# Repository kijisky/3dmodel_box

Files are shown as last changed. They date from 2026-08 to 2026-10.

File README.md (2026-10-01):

# Коробка для хранения метизов

Параметрическая 3D-модель (CadQuery) органайзера для метизов — винтов,
гаек, шайб и т.п. Рассчитана на печать на **ANYCUBIC Kobra S1**
(рабочая область 250×250×250 мм, CoreXY) плашмя, без поддержек.

## Модель сетки отсеков

Коробка делится на **строки** (по Y, вдоль длины). Каждая строка занимает
полную внутреннюю ширину коробки и делится на **свои** колонки (по X) —
независимо от других строк. Это значит:

- у разных строк может быть разное число ячеек;
- ширина каждой ячейки внутри строки задаётся независимо;
- сетка не обязана быть "таблицей" — ячейки соседних строк не обязаны
  совпадать по X.

## Параметры

| Параметр | CLI-флаг | По умолчанию | Описание |
|---|---|---|---|
| Ширина коробки | `--width` | 190 мм | внешний размер по X |
| Длина коробки | `--length` | 130 мм | внешний размер по Y |
| Высота (глубина) коробки | `--height` | 30 мм | внешний размер по Z |
| Толщина стенок | `--wall` | 2 мм | толщина внешних стенок, дна и перегородок |
| Число строк | `--rows` | 4 | строки идут по короткой стороне (Y) |
| Колонок в строке | `--cols` | 6 | одинаковое число колонок для всех строк (по длинной стороне, X) |
| Колонок по строкам | `--row-cols` | — | своё число колонок для каждой строки через запятую, напр. `3,6,6,6`; переопределяет `--cols` |
| Радиус скругления отсеков | `--radius` | 3 мм | скругление внутренних вертикальных углов каждой ячейки |
| Длины строк | `--row-sizes` | равномерно | список мм через запятую (по Y), переопределяет равное деление |
| Ширины ячеек по строкам | `--row-col-sizes` | равномерно | ширины каждой ячейки каждой строки (мм); группы строк разделены `\|`, ширины внутри строки — запятой |

По умолчанию получается коробка 190×130×30 мм: 4 строки по короткой
стороне (130 мм), в каждой строке по 6 колонок вдоль длинной стороны
(190 мм) — 24 одинаковых отсека.

Если заданы `--row-sizes` / `--row-col-sizes`, суммы значений должны точно
заполнять внутреннее пространство за вычетом перегородок:
`sum(sizes) == доступный_размер − толщина_стенки×(N−1)`, где
`доступный_размер = внешний_размер − 2×толщина_стенки`.
При несовпадении скрипт выбросит понятную ошибку с подсказкой.

## Крышка: шарнир + защёлка, стекирование

По умолчанию скрипт генерирует **три** STL: короб, крышку и шпильку
шарнира. Крышка **не снимается целиком** — она навешена на шарнир с одной
(длинной) стороны короба и открывается/закрывается поворотом, как у
чемодана; с противоположной стороны она держится защёлкой-замком, которую
можно отстегнуть.

- **Шарнир** (`hinge_wall`, по умолчанию `south`) — вдоль этой стенки на
  коробе и на крышке формируется ряд чередующихся цилиндрических петель
  (короб/крышка/короб/крышка/короб — `--hinge-knuckle-count`, по
  умолчанию 5), с общим отверстием под стержень. После печати в
  отверстия продевается отдельная деталь-шпилька (`..._pin.stl`,
  диаметр `--hinge-pin-diameter`, по умолчанию 3 мм — подходит кусок
  прутка, гвоздь без шляпки, спица или отрезок толстой лески/прутка от
  3D-принтера) — она и становится осью вращения. Отключается флагом
  `--no-hinge` — тогда крышка снова полностью съёмная, с защёлками со
  всех задействованных сторон (как раньше).
- **Защёлка-замок** — на противоположной шарниру стенке (и по умолчанию
  больше нигде) на внешней стенке короба формируется небольшой
  купол-выступ. В юбке крышки, ровно напротив него, с обеих сторон
  прорезаны узкие щели (`--snap-arm-gap`), отделяющие гибкий язычок
  шириной `--snap-arm-width` от остальной (жёсткой) юбки — держится он
  только сверху, на панели крышки, и может пружинить. На язычке —
  ответное углубление под выступ. Язычок продолжается ниже юбки на
  `--snap-tab-length` мм с небольшим наплывом наружу (`--snap-flare`) —
  этот выступающий кончик хорошо виден и удобно берётся пальцами.
  Чтобы отстегнуть: подцепите/отогните язычок наружу за выступающий
  кончик, пока выступ не выйдет из углубления, и откройте крышку на
  шарнире — инструмент не нужен, защёлка не ломается. Отключается флагом
  `--no-snap` (тогда крышка держится только посадкой с натягом на
  свободных от шарнира сторонах).
- **Стекирование** — на верхней стороне крышки формируется приподнятый
  бортик, внутренний размер которого равен внешнему периметру короба
  (+ зазор `--stack-clearance`). Следующий короб, поставленный сверху,
  дном садится внутрь этого бортика и не соскальзывает — короба стекуются
  друг на друга так же, как если бы каждый следующий просто стоял на
  предыдущем. Отключается флагом `--no-stacking`.

Дополнительные флаги шарнира: `--hinge-wall` (`north`/`south`/`east`/
`west` — какая стенка становится осью), `--hinge-knuckle-diameter`,
`--hinge-knuckle-count`, `--hinge-knuckle-gap` (зазор между соседними
петлями), `--hinge-margin` (отступ ряда петель от боковых стенок),
`--hinge-pin-clearance` (зазор шпильки в отверстии — свобода вращения).

Дополнительные флаги защёлки: `--snap-diameter`/`--snap-height` (размер
купола-выступа), `--snap-long`/`--snap-short` (число защёлок на длинных/
коротких стенках, кроме стенки шарнира), `--snap-arm-width` (ширина
гибкого язычка), `--snap-arm-gap` (ширина прорези, отделяющей язычок),
`--snap-tab-length` и `--snap-flare` (длина и наплыв выступающего кончика
для захвата).

Крышка и шпилька всегда должны генерироваться с теми же `--width/
--length/--height/--wall`, что и короб, к которому они предназначены —
иначе не подойдут.

## Установка

```bash
pip install -r requirements.txt
```

## Генерация STL

```bash
# модель по умолчанию (190x130x30, 4 строки x 6 колонок) + крышка на шарнире + шпилька
python3 models/fastener_box.py --out stl/fastener_box_190x130x30_6x4.stl
# -> ..._6x4.stl (короб), ..._6x4_lid.stl (крышка), ..._6x4_pin.stl (шпилька шарнира)

# шарнир на короткой стенке вместо длинной
python3 models/fastener_box.py --hinge-wall east --out stl/box_east_hinge.stl

# полностью съёмная крышка (без шарнира), как в предыдущей версии модели
python3 models/fastener_box.py --no-hinge --out stl/box_removable_lid.stl

# кастомные габариты и равномерная сетка
python3 models/fastener_box.py --width 200 --length 150 --height 40 \
  --wall 2.5 --rows 3 --cols 5 --radius 4 \
  --out stl/my_box.stl

# разное число ячеек в разных строках: в первой строке 3 широкие ячейки,
# в остальных трёх — по 6 обычных; крышка не нужна — та же, что у базовой модели
python3 models/fastener_box.py --row-cols 3,6,6,6 --no-lid \
  --out stl/fastener_box_190x130x30_mixed_rows.stl

# полностью произвольная сетка: своя высота строки, число ячеек и их
# ширина в каждой строке независимо (не таблица)
python3 models/fastener_box.py --rows 3 \
  --row-cols 2,4,1 \
  --row-sizes 40,42,40 \
  --row-col-sizes "100,84|30,50,40,60|186" \
  --no-lid --out stl/fastener_box_example_freeform.stl

# короб без крышки/защёлок/стекирования — просто открытый лоток
python3 models/fastener_box.py --no-lid --out stl/simple_tray.stl

# без защёлок (только посадка с натягом) или без бортика для стекирования
python3 models/fastener_box.py --no-snap --out stl/box_no_snap.stl
python3 models/fastener_box.py --no-stacking --out stl/box_no_stack.stl

# дополнительно сохранить STEP короба для редактирования в CAD
python3 models/fastener_box.py --step stl/fastener_box.step
```

Модель также можно импортировать программно:

```python
from models.fastener_box import build_fastener_box, build_lid, build_box_and_lid

# равномерная сетка, только короб
model = build_fastener_box(box_width=190, box_length=130, box_height=30,
                            wall_thickness=2, num_rows=4, row_cols=6,
                            corner_radius=3)

# произвольная сетка: 3 строки, разное число ячеек и их ширина в каждой
model = build_fastener_box(
    num_rows=3,
    row_cols=[2, 4, 1],              # число ячеек в каждой строке
    row_sizes=[40, 42, 40],          # высота (по Y) каждой строки
    row_col_sizes=[[100, 84], [30, 50, 40, 60], [186]],  # ширина ячеек в каждой строке
)

# короб + подходящая крышка + шпилька шарнира одним вызовом
# (используют общие box_* параметры; pin равен None при hinge_enabled=False)
base, lid, pin = build_box_and_lid(box_width=190, box_length=130, box_height=30,
                                    row_cols=6, num_rows=4)
```

## Готовые STL в этом репозитории

- `stl/fastener_box_190x130x30_6x4.stl` — короб по умолчанию (4 строки x 6 колонок, равномерная сетка), с петлями шарнира и защёлкой.
- `stl/fastener_box_190x130x30_6x4_lid.stl` — крышка к нему (на шарнире + защёлка + бортик для стекирования).
- `stl/fastener_box_190x130x30_6x4_pin.stl` — шпилька шарнира.
- `stl/fastener_box_190x130x30_mixed_rows.stl` — первая строка из 3 широких ячеек, остальные строки — по 6 обычных (короб напечатан без крышки, `--no-lid`; подходит под ту же крышку/шпильку).
- `stl/fastener_box_example_freeform.stl` — полностью произвольная сетка (разная высота строк, разное число и ширина ячеек в каждой строке; тоже без крышки, `--no-lid`).

## Рекомендации по печати (Kobra S1)

- Печать плашмя дном вниз, поддержки не требуются.
- Высота слоя 0.2 мм; толщина стенок 2 мм ≈ 5 периметров при сопле 0.4 мм —
  для меньшей толщины стенок уменьшайте число периметров соответственно.
- Заполнение 15–20 % достаточно, так как модель — по сути короб с тонкими
  стенками и перегородками.
- Скругления внутренних углов отсеков (по умолчанию 3 мм) облегчают
  выемку мелких деталей пальцами.
- Крышка тоже печатается плашмя, без поддержек (юбка обращена вниз, к столу).
- Зазор посадки крышки (`--fit-clearance`, по умолчанию 0.2 мм) рассчитан
  на типичную точность FDM с калиброванным принтером; если крышка садится
  слишком туго или слишком свободно — подстройте это значение под свой
  принтер и пластик (PLA/PETG).
- Защёлки цепляются выступом высотой `--snap-height` (по умолчанию
  0.7 мм) за язычок, отделённый от юбки прорезями `--snap-arm-gap`
  (по умолчанию 1 мм — печатается чисто соплом 0.4 мм за 2-3 прохода;
  меньше 0.6 мм может залипнуть/не прорезаться). Если язычок открывается
  слишком туго или слишком легко — увеличьте/уменьшите `--snap-arm-gap`
  (шире прорезь ⇒ мягче язычок) или `--snap-height` (глубже зацеп ⇒
  туже защёлка). Для очень жёстких пластиков (ABS) увеличьте
  `--snap-arm-width`, чтобы язычок оставался прочным при более мягком
  зацепе, либо отключите защёлки через `--no-snap`.
- Петли шарнира (диаметр `--hinge-knuckle-diameter`, по умолчанию 7 мм)
  печатаются как горизонтальные цилиндры-навесы плашмя вместе с
  остальной деталью — при диаметре в этих пределах Kobra S1 печатает их
  без поддержек. Отверстие под шпильку и сама шпилька — с зазором
  `--hinge-pin-clearance` (по умолчанию 0.3 мм) для свободного вращения;
  если петли после сборки крутятся туго — увеличьте зазор или слегка
  раздайте отверстие сверлом подходящего диаметра.
- В качестве шпильки подойдёт отрезок стержня/прутка/спицы диаметром
  `--hinge-pin-diameter` (по умолчанию 3 мм) чуть длиннее ряда петель —
  напечатанная деталь `..._pin.stl` даёт готовый ориентир по размеру,
  но для прочности лучше использовать металлический стержень, а не
  напечатанный (тонкий печатный пруток на изгиб слабее).

## Органайзер для батареек AA/AAA и «таблеток» (нижняя часть)

`models/battery_organizer.py` → `stl/battery_organizer.stl`. Круглые гнёзда, стоят вертикально, уложены «сотами».
Габариты 194×103×26 мм, **76 гнёзд**:

- AA — 8×5 = **40** шт. (гнёзда 15 мм, глубина 26 мм)
- AAA — 4×7 = **28** шт. (гнёзда 11 мм, глубина 24 мм)
- плоские — передний ряд из 8 прямоугольных (почти квадратных) ёмкостей ~22×24,5 мм со скруглёнными углами: стопку «таблеток» (CR2016/2025/2032/2450) можно вставить целиком; глубина 18 мм ≈ 5 шт. CR2032

Ускорение печати: стенка 1,2 мм (3 периметра сопла 0,4), нет сплошного дна — пол только под кольцами
гнёзд, щели между кольцами и у стенок сквозные; кольца AAA и «таблеток» ниже внешней стенки.
Без поддержек. Параметры: `--aa-cols --aa-rows --aaa-cols --aaa-rows --height --wall`;
диаметры плоских батареек — `coin_diameters` в `DEFAULTS`.

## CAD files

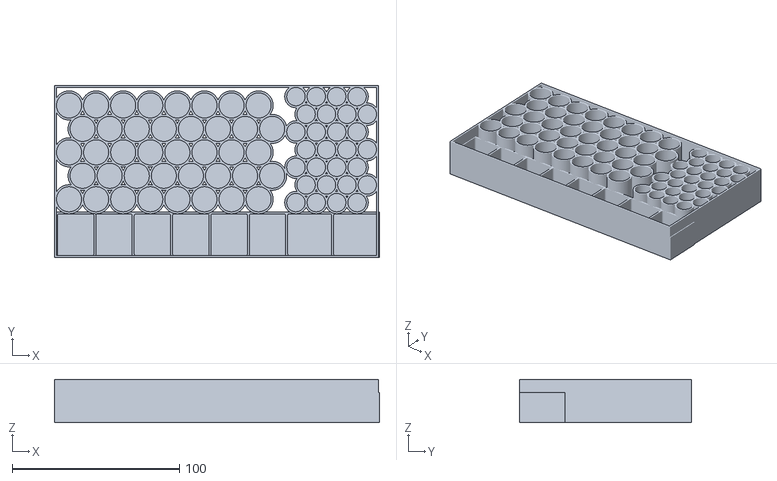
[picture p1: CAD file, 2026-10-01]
stl/battery_organizer.stl
194.4 x 103.0 x 26.0

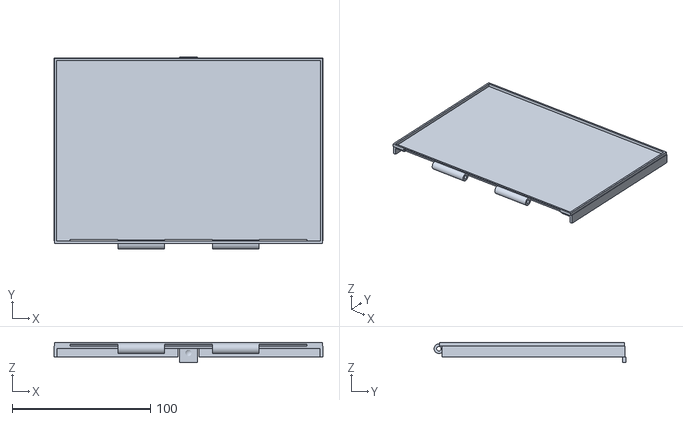
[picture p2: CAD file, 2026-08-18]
stl/fastener_box_190x130x30_6x4_lid.stl
194.4 x 138.6 x 14.5

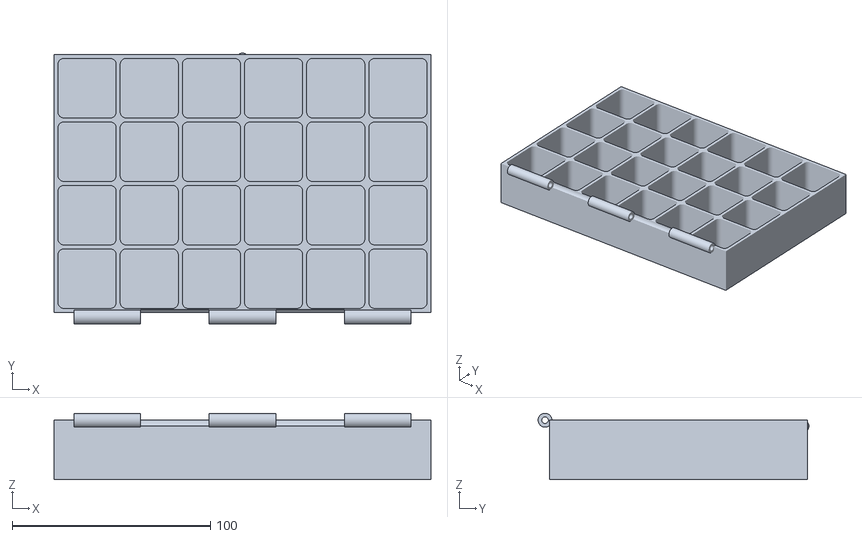
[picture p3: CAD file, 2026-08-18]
stl/fastener_box_190x130x30_6x4.stl
190.0 x 136.5 x 33.5

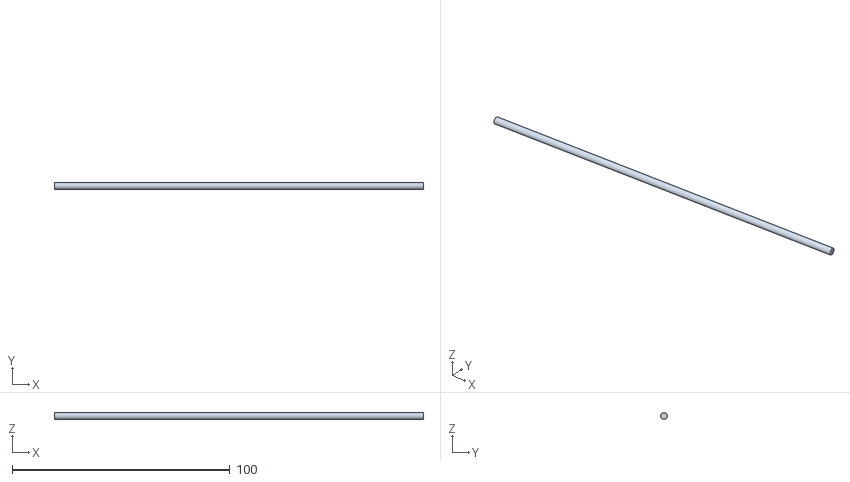
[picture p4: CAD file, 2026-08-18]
stl/fastener_box_190x130x30_6x4_pin.stl
169.5 x 3.00 x 3.00

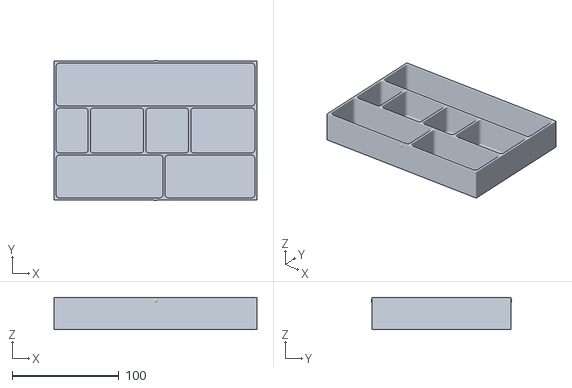
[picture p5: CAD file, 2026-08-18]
stl/fastener_box_example_freeform.stl
190.0 x 131.4 x 30.0

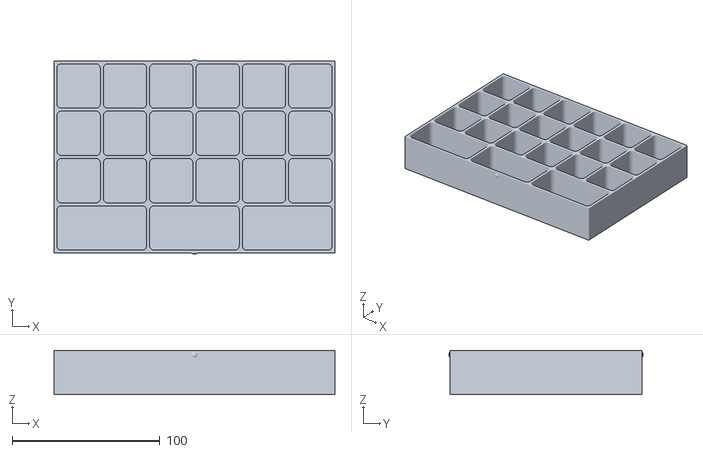
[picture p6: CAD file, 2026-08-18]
stl/fastener_box_190x130x30_mixed_rows.stl
190.0 x 131.4 x 30.0

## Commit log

2026-08-18 Add parametric fastener storage box CadQuery model
    Generates a compartmentalized organizer box for hardware (screws, nuts,
    washers) sized for the ANYCUBIC Kobra S1 print volume. Parameters cover
    box width/length/height, wall thickness, column/row count with optional
    per-column/row sizing, and internal compartment corner rounding.
    Defaults: 190x130x30 mm box with a 4x6 grid of equal-size compartments.
    Includes generated STL files and a README with usage/print notes.
    [fastener_box_190x130x30_4x6.stl, fastener_box_example_asymmetric.stl]
2026-08-18 Swap default grid orientation and support free-form per-row cell layout
    Default grid now runs 6 columns along the long side (190mm) and 4 rows
    along the short side (130mm), matching the intended layout.
    Reworked the compartment model from a fixed rows x cols table to
    independent rows: each row spans the full inner width and is divided
    into its own number of columns with its own widths, so different rows
    can have different cell counts and sizes without being constrained to
    align with other rows. CLI gains --row-cols and --row-col-sizes for
    this; --cols/--rows still cover the uniform-grid case.
    Regenerated STL set: default uniform 6x4 grid, a mixed-row example
    (first row 3 wide cells, rest 6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
    [fastener_box_190x130x30_4x6.stl, fastener_box_190x130x30_6x4.stl, fastener_box_190x130x30_mixed_rows.stl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]
2026-08-18 Add snap-fit lid and stacking to the fastener box
    The lid is a separate part: a flat panel with a downward skirt that
    slides over the box's outer walls (parametrized fit clearance). Small
    dome bumps on the box exterior mate with matching pockets in the lid
    skirt for a tactile snap that resists accidental removal but still
    opens by hand.
    For stacking, the lid's top face gets a raised registration lip sized
    to the box's own outer footprint (plus clearance), so a second box's
    base drops into it and self-centers, letting boxes stack the same way
    they'd sit on a table.
    Both features are on by default and can be disabled independently
    (--no-snap, --no-stacking, --no-lid). Added build_lid()/build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
    [fastener_box_190x130x30_6x4.stl, fastener_box_190x130x30_6x4_lid.stl, fastener_box_190x130x30_mixed_rows.stl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]
2026-08-18 Make the lid latch an actual releasable clip, not just an embedded bump
    The previous snap detent was cast into the rigid, continuous skirt
    ring, which barely flexes as a whole — functionally it was closer to
    a stiff press-fit than a latch you can release by hand, which is
    presumably why it wasn't registering as a real "latch-lock".
    add_latch_arms() now cuts two narrow freeing slots into the skirt on
    either side of each snap position, isolating a flexible tab (fixed
    only at the top, where it joins the lid plate) that can actually
    flex open. The tab extends past the skirt's bottom edge with a slight
    outward flare, giving it a visible, grippable end to pull/flex when
    unlatching. New knobs: s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
    [fastener_box_190x130x30_6x4.stl, fastener_box_190x130x30_6x4_lid.stl, fastener_box_190x130x30_mixed_rows.stl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]
2026-08-18 Add a knuckle hinge with a separate pin, latch stays on the opposite side
    Per request: lid is no longer fully removable — it's hinged on one wall
    (default: south, the long back wall) and secured on the opposite wall
    by the existing releasable latch, like a toolbox lid.
    Hinge is a classic interleaved knuckle joint: alternating cylindrical
    knuckles (box/lid/box/lid/box by default) along the chosen wall, each
    bored for a pin; a separate printable pin part (also just a reasonable
    reference size — a metal rod/spoke is recommended for strength) is
    inserted through all of them after printing to form the pivot. Added
    add_hinge(), _hinge_geometry(), _tangent_cylinder(), _remove_wall_skirt()
    and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
    [fastener_box_190x130x30_6x4.stl, fastener_box_190x130x30_6x4_lid.stl, fastener_box_190x130x30_6x4_pin.stl]
2026-10-01 Add thin-wall AA/AAA battery organizer (base only)
    Claude-Session: https://claude.ai/code/session_01D3usdnMeYNEDddDJedfoJb
    [battery_organizer.stl]
2026-10-01 Battery organizer: more AA (40), fewer AAA (21)
    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
    [battery_organizer.stl]
2026-10-01 Battery organizer: larger, more AAA, coin-cell row, lighter print
    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
    [battery_organizer.stl]
2026-10-01 Battery organizer: square bins for coin cells
    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
    [battery_organizer.stl]
